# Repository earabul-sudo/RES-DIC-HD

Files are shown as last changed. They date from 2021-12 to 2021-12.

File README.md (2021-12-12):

# Residual Stress Measurement Device using Hole Drilling Method and Digital Image Correlation
 Complete documentation (CAD, Software, Instructions) of a novel Residual Stress Measurement Device utilising Hole Drilling Method and Digital Image Correlation



The CAD Model for the device can be found in the link:
https://a360.co/3m0amRs

For getting started using the device, follow the instructions manual.

Links to additional software used:

  Device/Data Acquisation Related:
  
https://github.com/grbl/grbl (Grbl Gcode parser)

https://github.com/winder/Universal-G-Code-Sender (GUI for Grbl)

https://www.theimagingsource.com/support/downloads-for-windows/end-user-software/icmeasure/ (For capturing images and viewing using camera)

  DIC/Evaluation Related:
  
http://www.ncorr.com/ (Main DIC Software used)

http://mech.fsv.cvut.cz/~nezerka/DIC/index.htm (Plugin for ncorr, allows for creating virtual extensometers)

https://uk.mathworks.com/matlabcentral/fileexchange/50994-digital-image-correlation-and-tracking (Another DIC software, used image averaging functionality in the measurements)

https://imagej.nih.gov/ij/ (Useful tool for image averaging/rigid body corrections)

https://www.irfanview.com/ (Useful tool for batch processing images)

For any issues, contact Ege Arabul (ege.arabul@bath.edu)

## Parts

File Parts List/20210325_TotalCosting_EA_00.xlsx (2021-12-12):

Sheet: Act. Cost
No | Subsystem | Quantity | Part Name | Cost per piece | Total Cost
1 | DIC System | 1 | HAYEAR 48MP Digital Industrial Video Microscope Camera + 100X C-mount Lens + 56 LED Ring Light For Soldering Repair+ Stand Holder | 108.55 | 108.55
2 |  | 1 | 110V-220V 56 LED Ring Light | £16.26 | 16.26
3 | Drilling System | 1 | TACKLIFE Rotary Tool Kit | 35.99 | 35.99
4 |  | 1 | 1.6mm Tungsten Carbide PCB Drill Bit | 8.59 | 8.59
5 | Speckle Pattern Application | 1 | Plasti-kote 3101 400ml Super Spray Paint - Matt Black | £9.34 | 9.34
6 |  | 1 | Plasti-kote 3100SE 400ml Super Matt Spray Paint - White | £5.02 | 5.02
7 | The Actuation | 2 | T8 Trapezoidal Lead Screw Lead Screw + T8 Nut | £8.99 | 17.98
8 |  | 2 | 5mm to 8mm Shaft Coupling | £6.49 | 12.98
9 |  | 2 | Nema 17 Stepper Motor | £10.00 | 20
10 |  | 4 | LML12B Miniature Linear Rail Guide 150 | £14.49 | 57.96
11 |  | 2 | EasyDriver Shield Stepper Motor Driver | £5.99 | 11.98
12 |  | 1 | Mechanical Endstop Limit Switch | £6.99 | 6.99
13 |  | 1 | Arduino Uno | £9.99 | 9.99
14 |  | 1 | Lithium Grease | £5.06 | 5.06
15 | Chip Blower | 1 | One Channel Relay | £1.50 | 1.5
16 |  | 1 | Micro Air Pump - DC 12V Micro Vacuum Pump, Electric Mini Air Pumping Booster for Treatment Instrument | £13.10 | 13.1
17 |  | 1 | Mist Lubrication Coolant Spray System | £5.59 | 5.59
18 | Zero Depth Detection | 1 | Alligator Clips Clamps | £1.99 | 1.99
19 | Sample Attachment | 1 | 52 mm suction cup with M4 screw | £6.49 | 6.49
20 | Packaging | 26 | RS PRO 15 x 15mm 2 Hole Steel Angle Bracket | 0.183 | 4.758
21 |  | 1 | RS PRO M3 x 12mm Hex Socket Cap Screw Black, Self-Colour Steel (Pack of 100) | 13.98 | 13.98
22 |  | 1 | RS PRO Steel, Hex Nut, M3 | 4.02 | 4.02
23 |  | 1 | Zinc Plated Steel Plain Washer, 0.5mm Thickness, M3 | 1.11 | 1.11
24 |  | 1 | Manufacturing Expenses (for the Final prototype) | 50 | 50
 |  |  |  | Total Cost | 429.228

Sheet: Red. Cost
No | Subsystem | Quantity | Part Name | Cost per piece | Total Cost
1 | DIC System | 1 | HAYEAR 48MP Microscope Camera + 100X C-mount Lens + 56 LED Ring Light For Soldering Repair+ Stand Holder | 108.55 | 108.55
2 | Drilling System | 1 | TACKLIFE Rotary Tool Kit | 35.99 | 35.99
3 |  | 1 | 1.6mm Tungsten Carbide PCB Drill Bit | 8.59 | 8.59
4 | Speckle Pattern Application | 1 | Plasti-kote 3101 400ml Super Spray Paint - Matt Black | £5.02 | 5.02
5 |  | 1 | Plasti-kote 3100SE 400ml Super Matt Spray Paint - White | £5.02 | 5.02
6 | The Actuation | 2 | T8 Trapezoidal Lead Screw Lead Screw + T8 Nut | £8.99 | 17.98
7 |  | 2 | 5mm to 8mm Shaft Coupling | £6.49 | 12.98
8 |  | 2 | Nema 17 Stepper Motor | £10.00 | 20
9 |  | 4 | LML12B Miniature Linear Rail Guide 150 | £7.99 | 31.96
10 |  | 2 | EasyDriver Shield Stepper Motor Driver | £5.99 | 11.98
11 |  | 1 | Mechanical Endstop Limit Switch | £6.99 | 6.99
12 |  | 1 | Arduino Uno | £9.99 | 9.99
13 |  | 1 | Lithium Grease | £5.06 | 5.06
14 | Zero Depth Detection | 1 | Alligator Clips Clamps | £1.99 | 1.99
15 | Sample Attachment | 1 | 52 mm suction cup with M4 screw | £6.49 | 6.49
16 | Packaging | 26 | RS PRO 15 x 15mm 2 Hole Steel Angle Bracket | 0.183 | 4.758
17 |  | 1 | RS PRO M3 x 12mm Hex Socket Cap Screw Black, Self-Colour Steel (Pack of 100) | 13.98 | 13.98
18 |  | 1 | RS PRO Steel, Hex Nut, M3 | 4.02 | 4.02
19 |  | 1 | Zinc Plated Steel Plain Washer, 0.5mm Thickness, M3 | 1.11 | 1.11
20 |  | 1 | Manufacturing Expenses (for the Final prototype) | 50 | 50
 |  |  |  | Total Cost | 362.458

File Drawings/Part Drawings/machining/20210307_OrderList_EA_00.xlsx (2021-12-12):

No | Quantity | Part Name | Description | Not Yet Completed/ Completed
1 | 2 | 20210305_LeadScrewNut_EA_00 | LeadScrew Nut
2 | 1 | 20210302_CameraHolder | Camera Holder
3 | 3 | 20212026_SpacerRods_EA_100mm_00 Drawing | Spacer 100mm
4 | 3 | 20212026_SpacerRods_EA_50mm_00 | Spacer 50mm
5 | 3 | 20210226_SpacerBottom_EA_00 | Spacer Bottom
6 | 3 | AB90B_M-Step | Custom Angle Bracket

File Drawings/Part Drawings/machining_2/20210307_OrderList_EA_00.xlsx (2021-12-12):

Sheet: Order_1
No | Quantity | Part Name | Description | Not Yet Completed/ Completed
1 | 2 | 20210305_LeadScrewNut_EA_00 | LeadScrew Nut
2 | 1 | 20210302_CameraHolder | Camera Holder
3 | 3 | 20212026_SpacerRods_EA_100mm_00 Drawing | Spacer 100mm
4 | 3 | 20212026_SpacerRods_EA_50mm_00 | Spacer 50mm
5 | 3 | 20210226_SpacerBottom_EA_00 | Spacer Bottom
6 | 3 | AB90B_M-Step | Custom Angle Bracket

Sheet: Order_2
No | Quantity | Part Name | Description | Not Yet Completed/ Completed
1 | 1 | 20210316_BreadboardBase_EA_00 | Breadboard Mounting Base
2 | 2 | 20210317_JawClamp_1Clamp_EA_00 | Clamp to attach to Breadboard
3 | 1 | 20210317_JawClamp_2Clamps_EA_00 | Clamp to attach to Breadboard
4 | 3 | 20212026_SpacerRods_EA_50mm_00 | Modification to previously made spacers. Parts will be provided
5 | 3 | 20212026_SpacerRods_100mm_EA_00 | Modification to previously made spacers. Parts will be provided
6 | 3 | 20212026_SpacerRods_EA_125mm_00 | Spacer 125 mm
7 | 3 | 20212026_SpacerRods_EA_200mm_00 | Spacer 200 mm

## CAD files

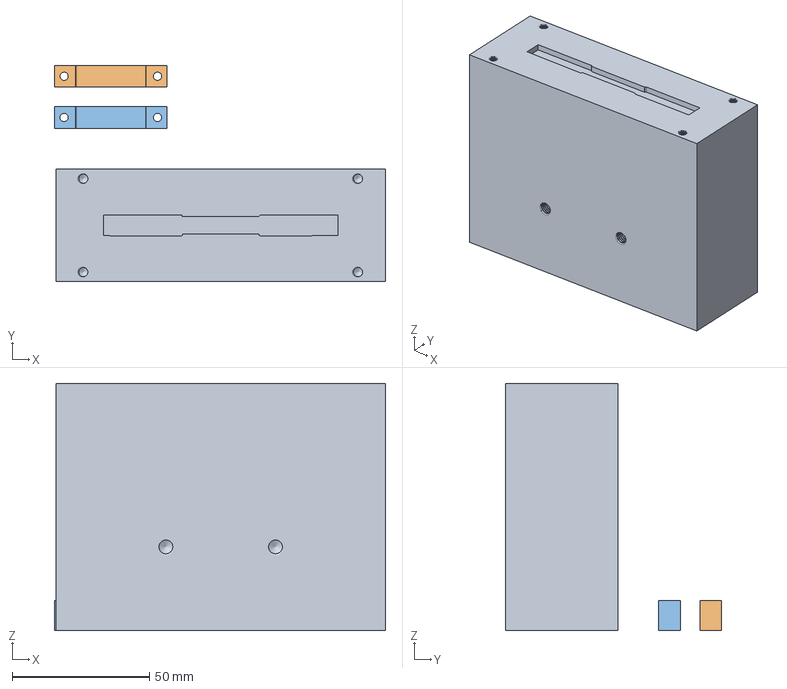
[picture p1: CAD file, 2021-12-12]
Drawings/Part Drawings/3dprint_clamps/CE3PRO_20210302_SecondPrototype2_Assembly_Additiv_Cont_EA_00_20210513_FlexHolder_EA_00 v6.3mf
120.5 x 78.8 x 90.0 mm
20210302_SecondPrototype2_Assembly_Additiv_Cont_EA_00_20210513_FlexHolder_EA_00 v6.stl
20210513_FlexHolderClamp_EA_00 v2.stl
20210513_FlexHolderClamp_EA_00 v2.stl(1)

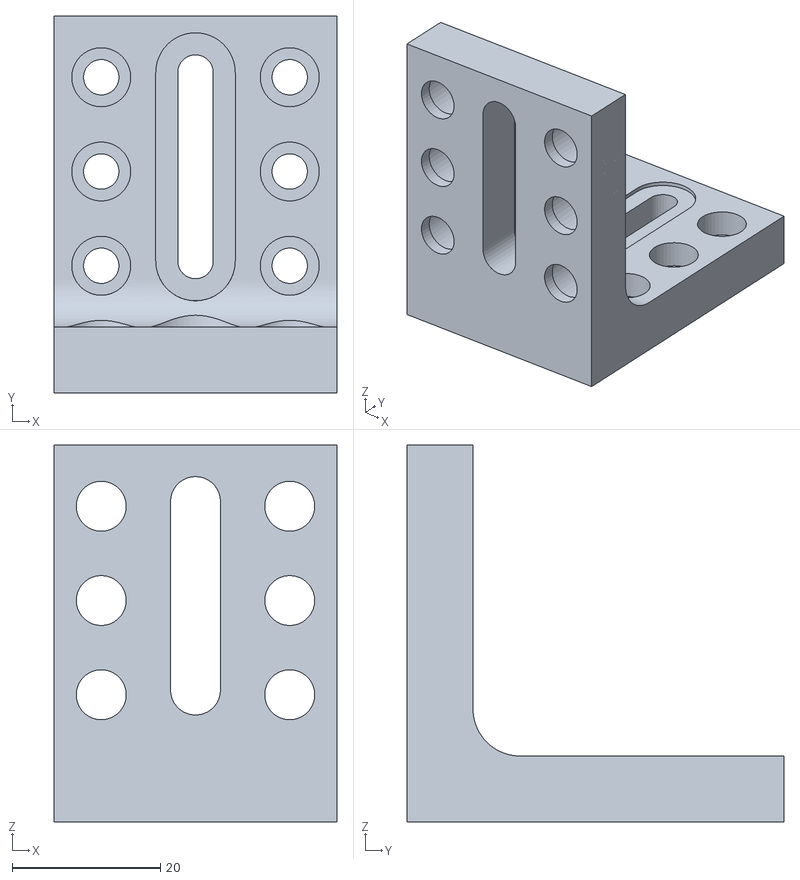
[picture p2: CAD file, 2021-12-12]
Drawings/Part Drawings/3dprint_clamps/AB90D-Step v2.stl
38.1 x 50.8 x 50.8

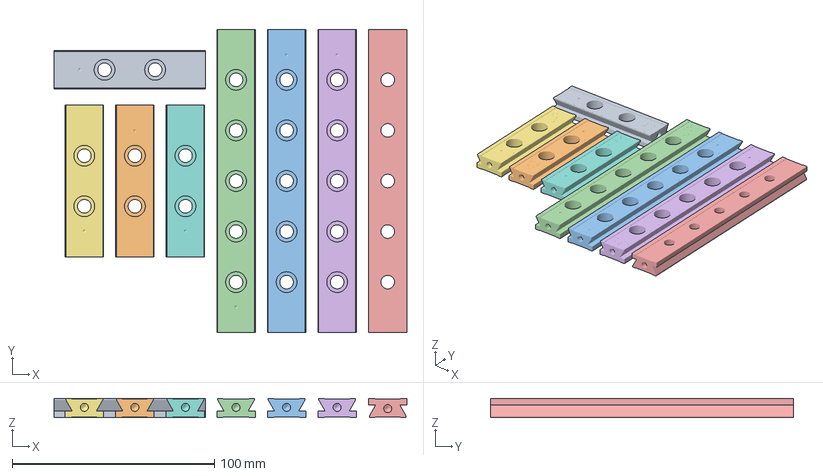
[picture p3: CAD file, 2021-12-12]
Drawings/Part Drawings/3dprint_clamps/CE3PRO_RLA075_M-Step v1.4mf.3mf
174.5 x 150.0 x 9.53 mm
RLA075_M-Step v1.stl
RLA075_M-Step v1.stl(1)
RLA150_M-Step v1.stl
RLA150_M-Step v1.stl(1)
RLA150_M-Step v1.stl(2)
RLA150_M-Step v1.stl(3)
RLA075_M-Step v1.stl(2)
RLA075_M-Step v1.stl(3)

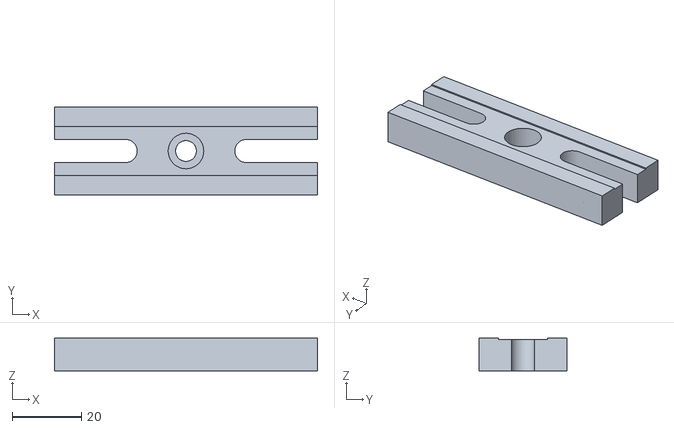
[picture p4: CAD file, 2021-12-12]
Drawings/Part Drawings/3dprint_clamps/BA1V-Step v3.stl
76.2 x 25.4 x 9.53

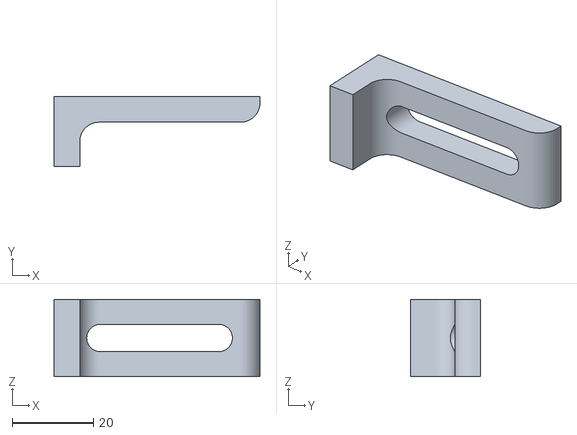
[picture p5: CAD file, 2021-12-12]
Drawings/Part Drawings/3dprint_clamps/CL5-Step v1.stl
50.8 x 17.3 x 19.1

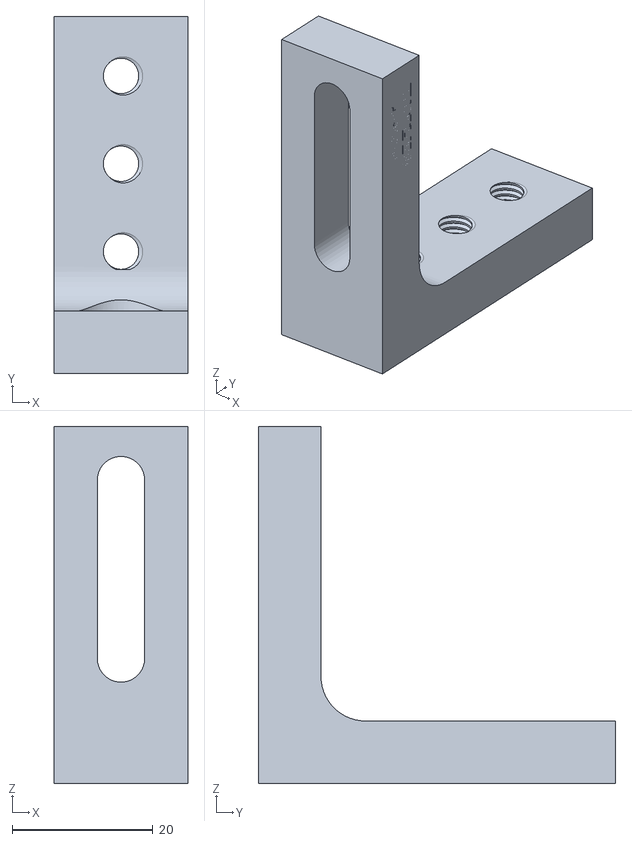
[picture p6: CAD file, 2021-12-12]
Drawings/Part Drawings/3dprint_clamps/AB90C_M-Step v2.stl
19.0 x 50.8 x 50.8

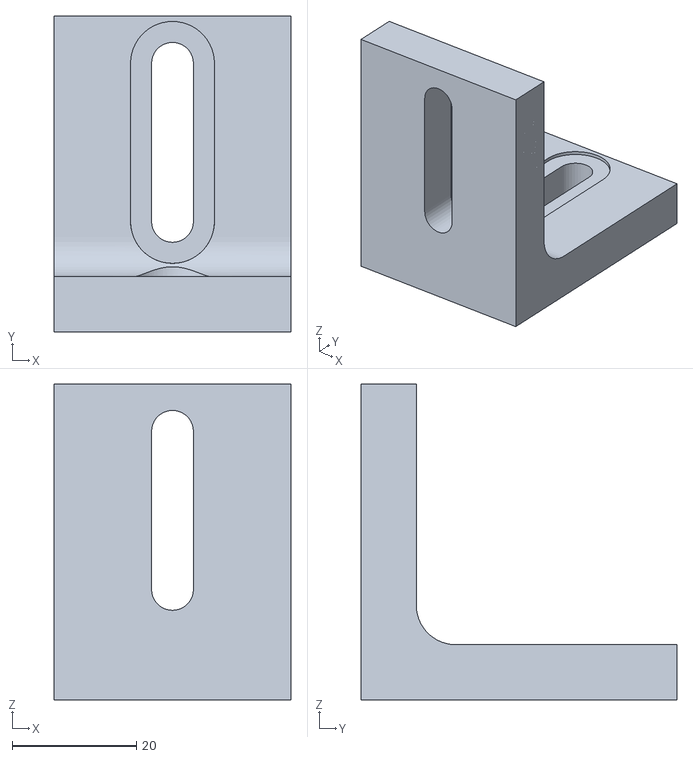
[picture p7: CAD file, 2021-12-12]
Drawings/Part Drawings/3dprint_clamps/AB90-Step v1.stl
38.1 x 50.8 x 50.8

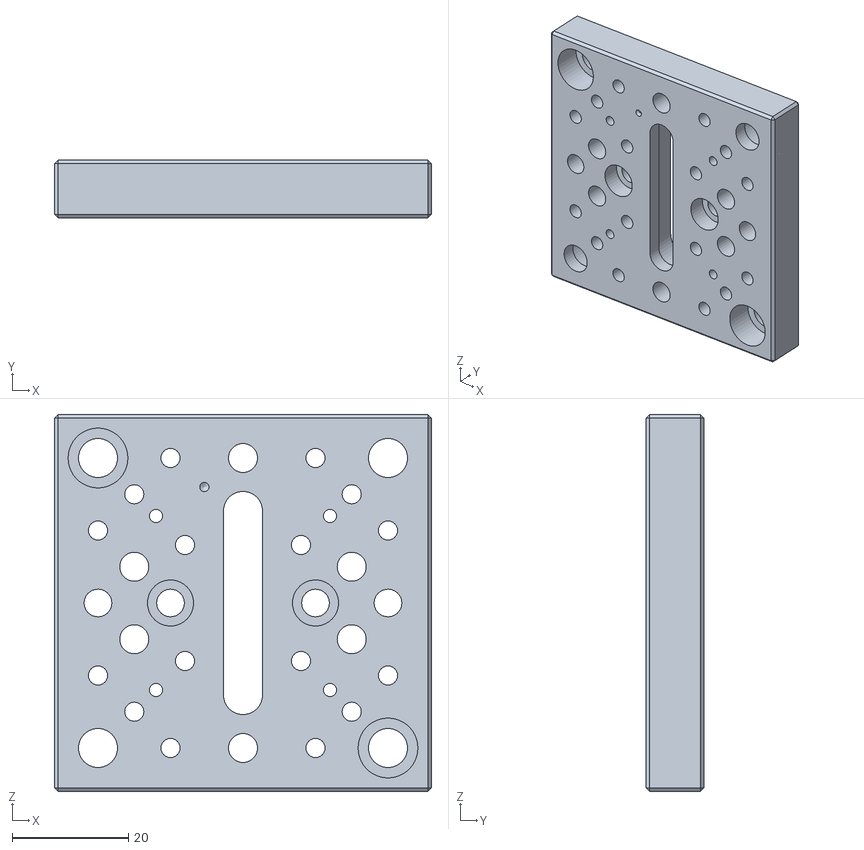
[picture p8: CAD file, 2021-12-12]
Drawings/Part Drawings/3dprint_clamps/UBP2_M-Step v1.stl
65.0 x 10.0 x 65.0

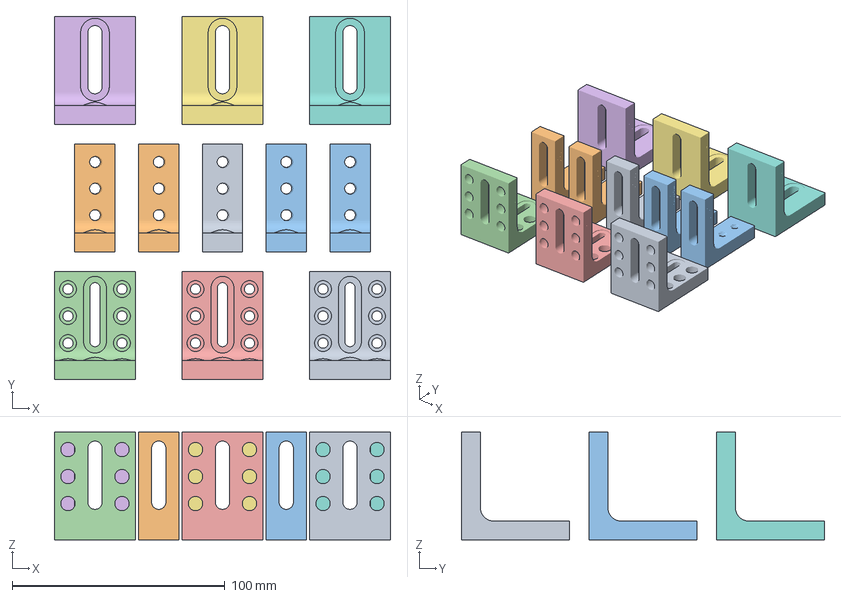
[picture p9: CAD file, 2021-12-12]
Drawings/Part Drawings/3dprint_clamps/CE3PRO_AB90C_M-Step v2.3mf
158.1 x 170.8 x 50.8 mm
AB90C_M-Step v2.stl
AB90C_M-Step v2.stl(1)
AB90C_M-Step v2.stl(2)
AB90D-Step v2.stl
AB90D-Step v2.stl(1)
AB90-Step v1.stl
AB90-Step v1.stl(1)
AB90-Step v1.stl(2)
AB90D-Step v2.stl(2)
AB90C_M-Step v2.stl(3)
AB90C_M-Step v2.stl(4)

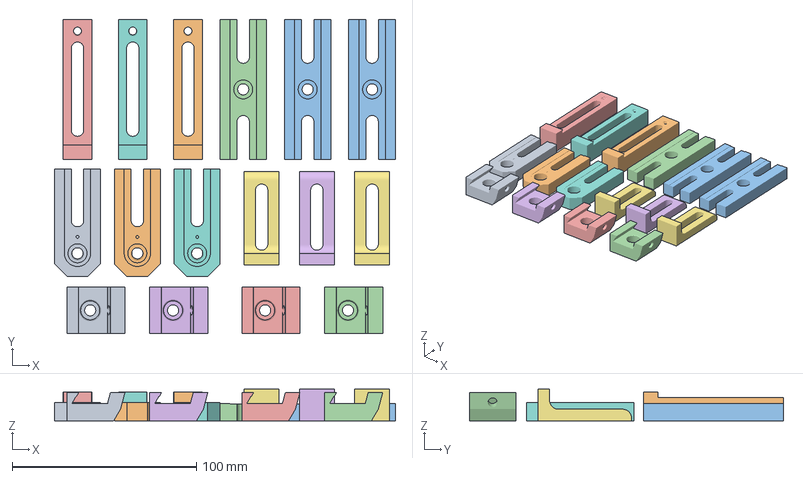
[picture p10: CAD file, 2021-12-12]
Drawings/Part Drawings/3dprint_clamps/CE3PRO_BA1SV_M-Step v2.3mf
185.2 x 170.8 x 17.3 mm
BA1SV_M-Step v2.stl
BA1SV_M-Step v2.stl(1)
BA1V-Step v3.stl
BA1V-Step v3.stl(1)
CL2_M-Step v3.stl
CL5-Step v1.stl
CL5-Step v1.stl(1)
CL2_M-Step v3.stl(1)
RC1-Step v5.stl
CL2_M-Step v3.stl(2)
BA1V-Step v3.stl(2)
RC1-Step v5.stl(1)
RC1-Step v5.stl(2)
RC1-Step v5.stl(3)
CL5-Step v1.stl(2)
BA1SV_M-Step v2.stl(2)

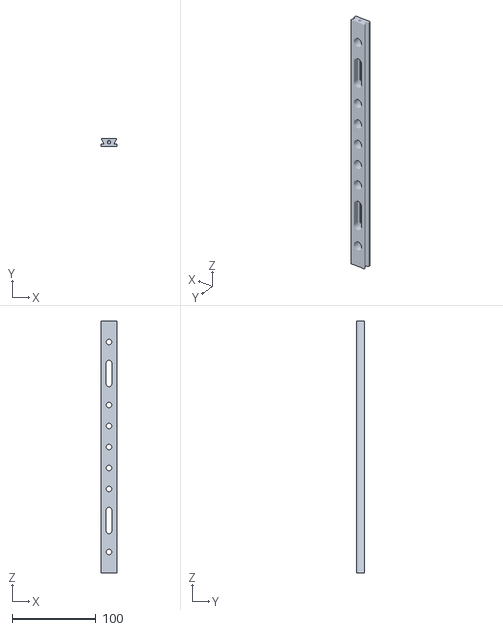
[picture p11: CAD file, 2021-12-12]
Drawings/Part Drawings/3dprint_clamps/RLA300_M-Step v1.stl
19.0 x 9.53 x 300.0

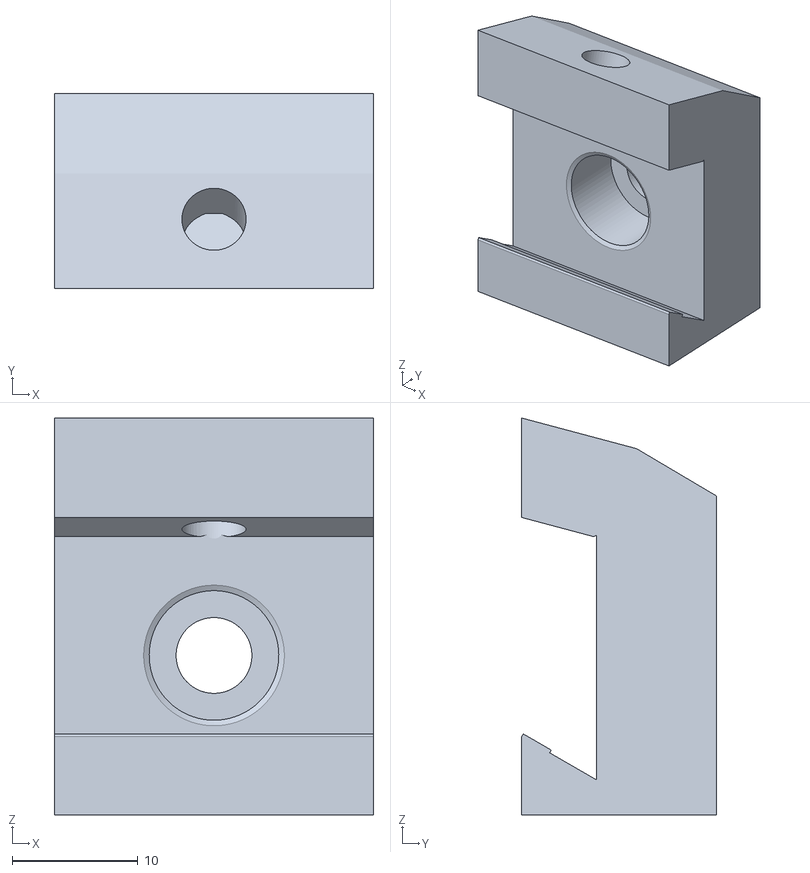
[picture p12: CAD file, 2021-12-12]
Drawings/Part Drawings/3dprint_clamps/RC1-Step v5.stl
25.4 x 15.5 x 31.6

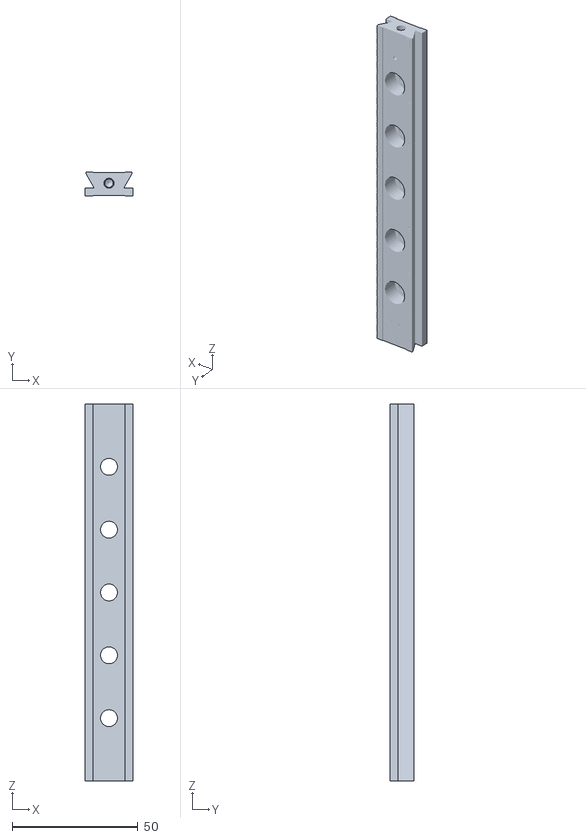
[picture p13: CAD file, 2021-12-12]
Drawings/Part Drawings/3dprint_clamps/RLA150_M-Step v1.stl
19.0 x 9.53 x 150.0

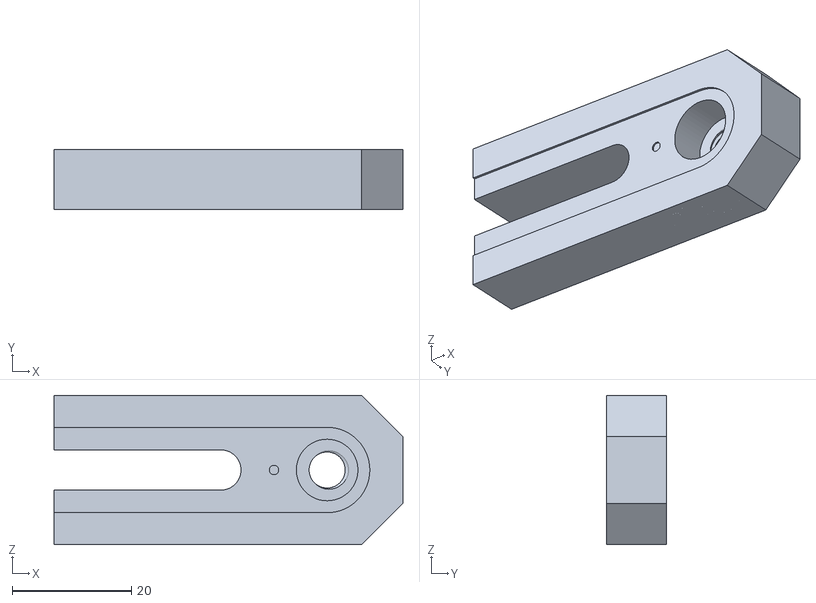
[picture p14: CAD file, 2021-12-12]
Drawings/Part Drawings/3dprint_clamps/BA1SV_M-Step v2.stl
58.4 x 10.0 x 25.0

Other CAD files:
Drawings/Part Drawings/3dprint_clamps/RLA075_M-Step v1.stl
Drawings/Part Drawings/3dprint_clamps/CL2_M-Step v3.stl
Drawings/Part Drawings/3dprint_clamps/20210302_SecondPrototype2_Assembly_Additiv_Cont_EA_00_20210513_FlexHolder_EA_00 v6.stl
Drawings/Part Drawings/3dprint_clamps/20210302_SecondPrototype2_Assembly_Additiv_Cont_EA_00_20210513_FlexHolder_Long_EA_00 v3.stl
Drawings/Part Drawings/3dprint_clamps/20210513_FlexHolderClamp_EA_00 v1.stl
Drawings/Part Drawings/3dprint_clamps/20210513_FlexHolderClamp_EA_00 v2.stl
Drawings/Part Drawings/3dprint_clamps/20210513_FlexHolder_EA_00 v4.stl

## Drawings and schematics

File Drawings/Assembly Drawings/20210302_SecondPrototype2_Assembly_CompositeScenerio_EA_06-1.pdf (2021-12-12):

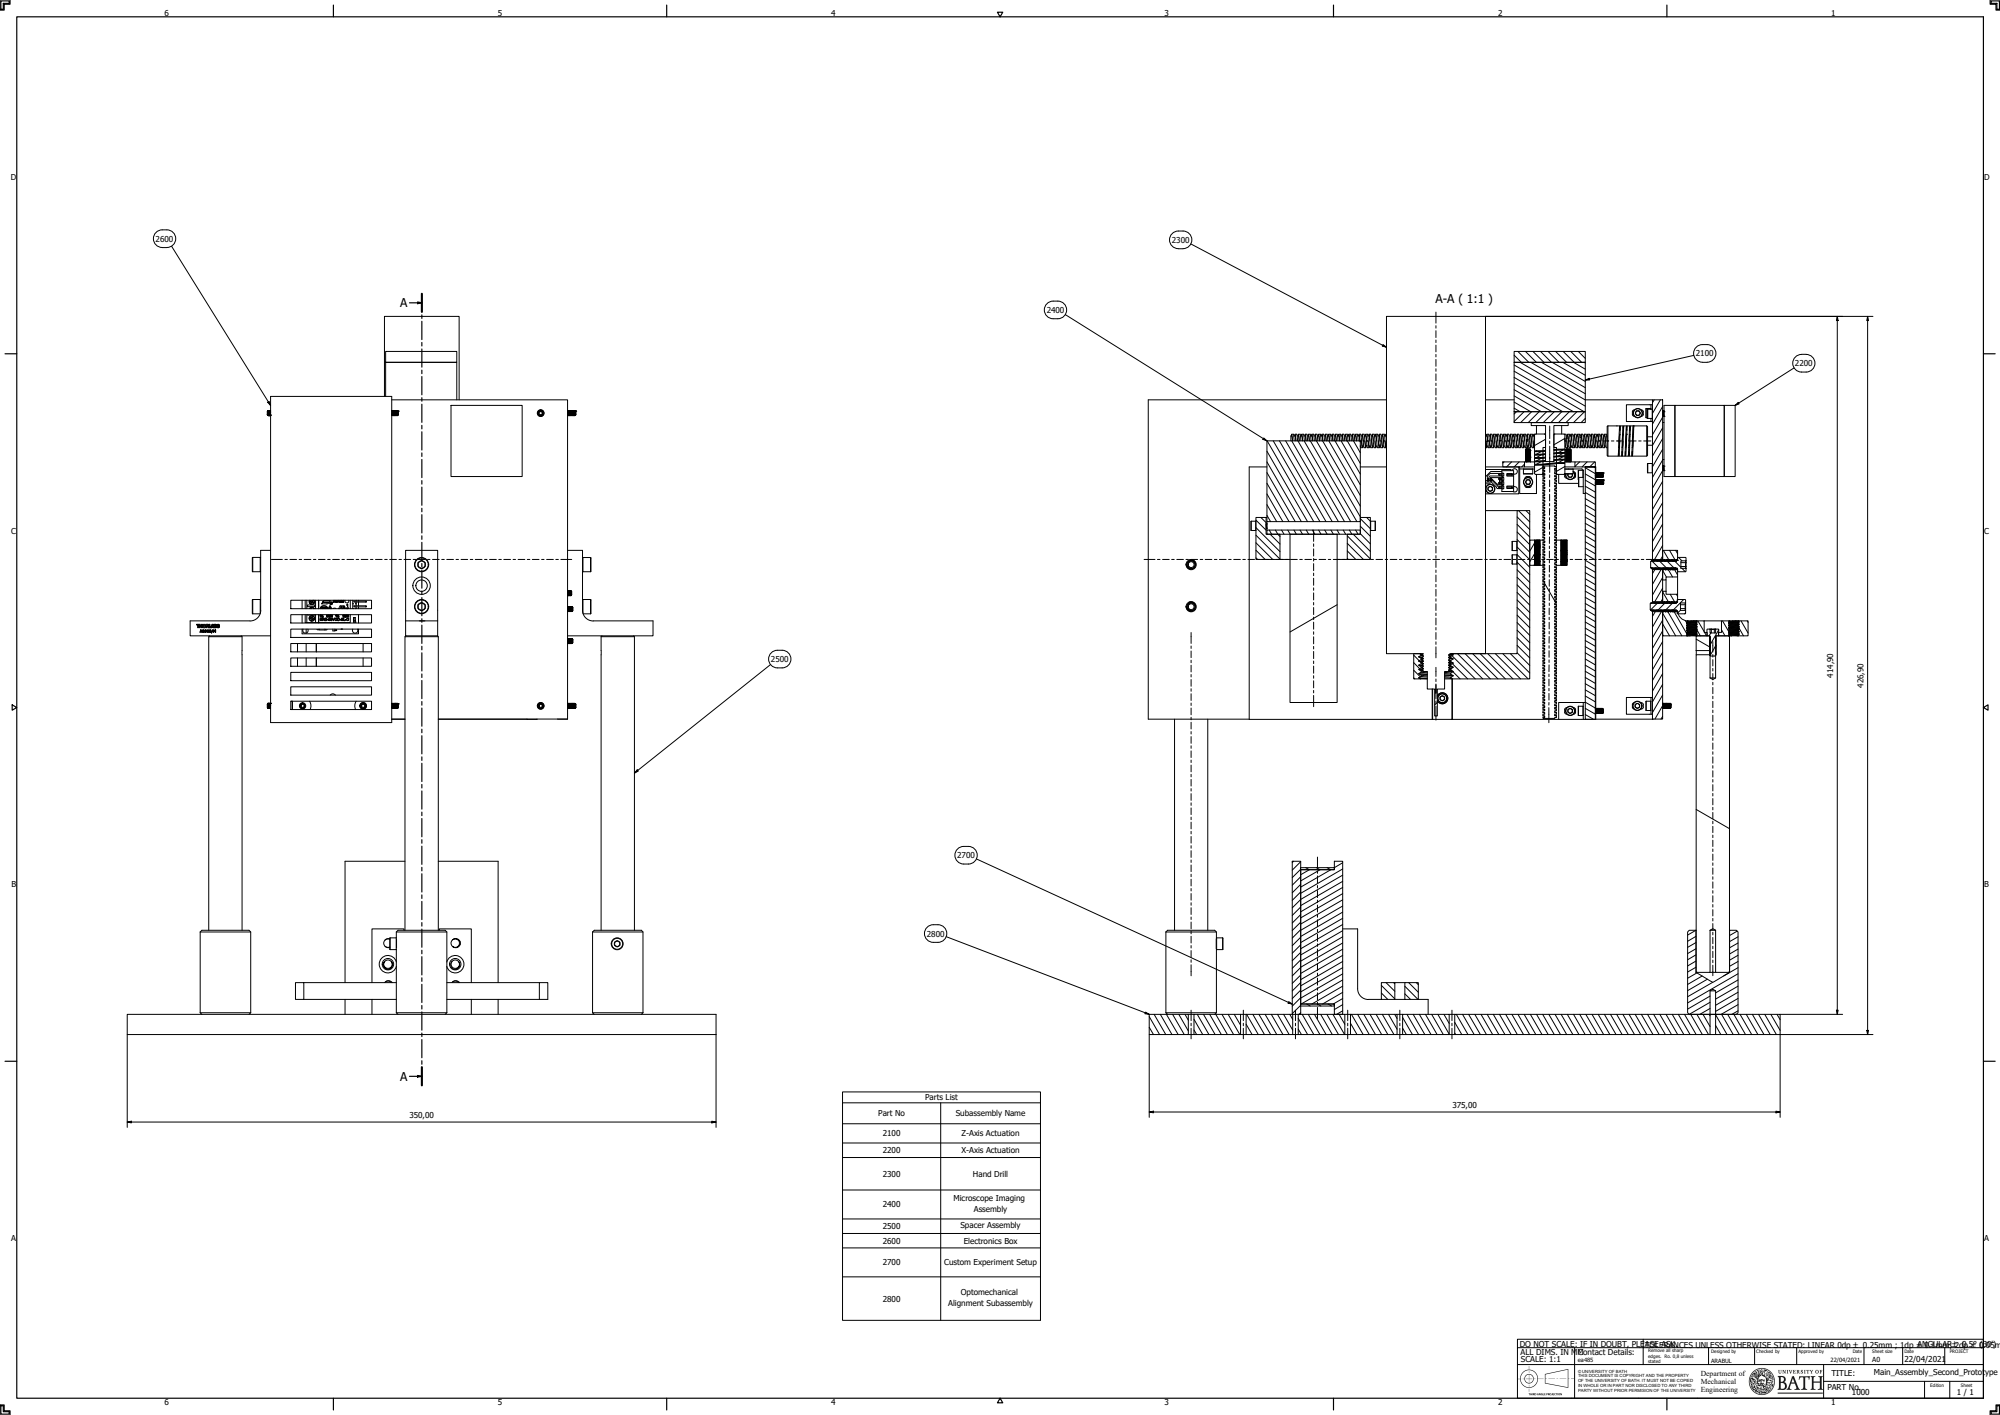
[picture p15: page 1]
Designed by; Checked by; Approved by; Date; Department of; SCALE: 1:1; Sheet size; PART No.; Contact Details:; Parts List; Part No; Subassembly Name; Z-Axis Actuation; X-Axis Actuation; Hand Drill; Microscope Imaging; Spacer Assembly; Electronics Box; Custom Experiment Setup; Alignment Subassembly

DO NOT SCALE: IF IN DOUBT, PLEASE ASK.
ALL DIMS. IN MM

TOLERANCES UNLESS OTHERWISE STATED: LINEAR 0dp  0.25mm ; 1dp ±AN0G.1UmLAmR;2d0p.5±° 0(3.005')mm

Remove all sharp
edges. Ro. 0,8 unless
stated

© UNIVERSITY OF BATH
THIS DOCUMENT IS COPYRIGHT AND THE PROPERTY
OF THE UNIVERSITY OF BATH. IT MUST NOT BE COPIED
IN WHOLE OR IN PART NOR DISCLOSED TO ANY THIRD
PARTY WITHOUT PRIOR PERMISION OF THE UNIVERSITY

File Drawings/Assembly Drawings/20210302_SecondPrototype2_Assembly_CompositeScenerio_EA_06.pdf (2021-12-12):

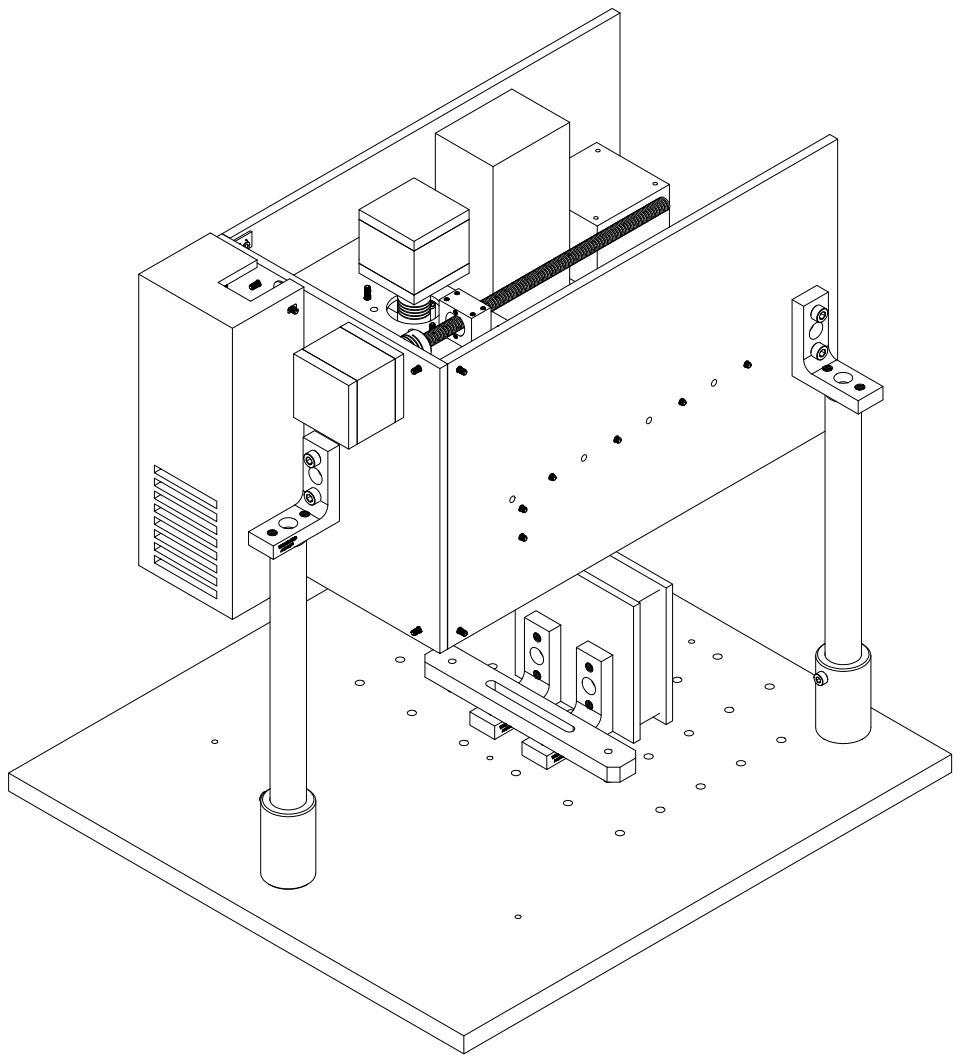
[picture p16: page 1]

DO NOT SCALE | TOLERANCES: LINEAR 0dp  0.25mm ; 1dp ± 0.1mm; 2dp ± 0.05mm ANGULAR 0.5° (30')
DIMS. IN MM SCALE: 1 : 1 | Contact Details: ea485 | Remove all sharp edges. Ro. 0,8 unless stated | Designed by ARABUL | Checked by | Approved by Date 22/04/2021 | Sheet size A0 | Date 22/04/2021 | PROJECT

© UNIVERSITY OF BATH THIS DOCUMENT IS COPYRIGHT AND THE PROPERTY OF THE UNIVERSITY OF BATH. IT MUST NOT BE COPIED IN WHOLE OR IN PART NOR DISCLOSED TO ANY THIRD PARTY WITHOUT PRIOR PERMISION OF THE UNIVERSITY | Department of Mechanical Engineering | TITLE: Main Assembly_Isometric

PART No. 1000 | Edition | Sheet 1 / 1

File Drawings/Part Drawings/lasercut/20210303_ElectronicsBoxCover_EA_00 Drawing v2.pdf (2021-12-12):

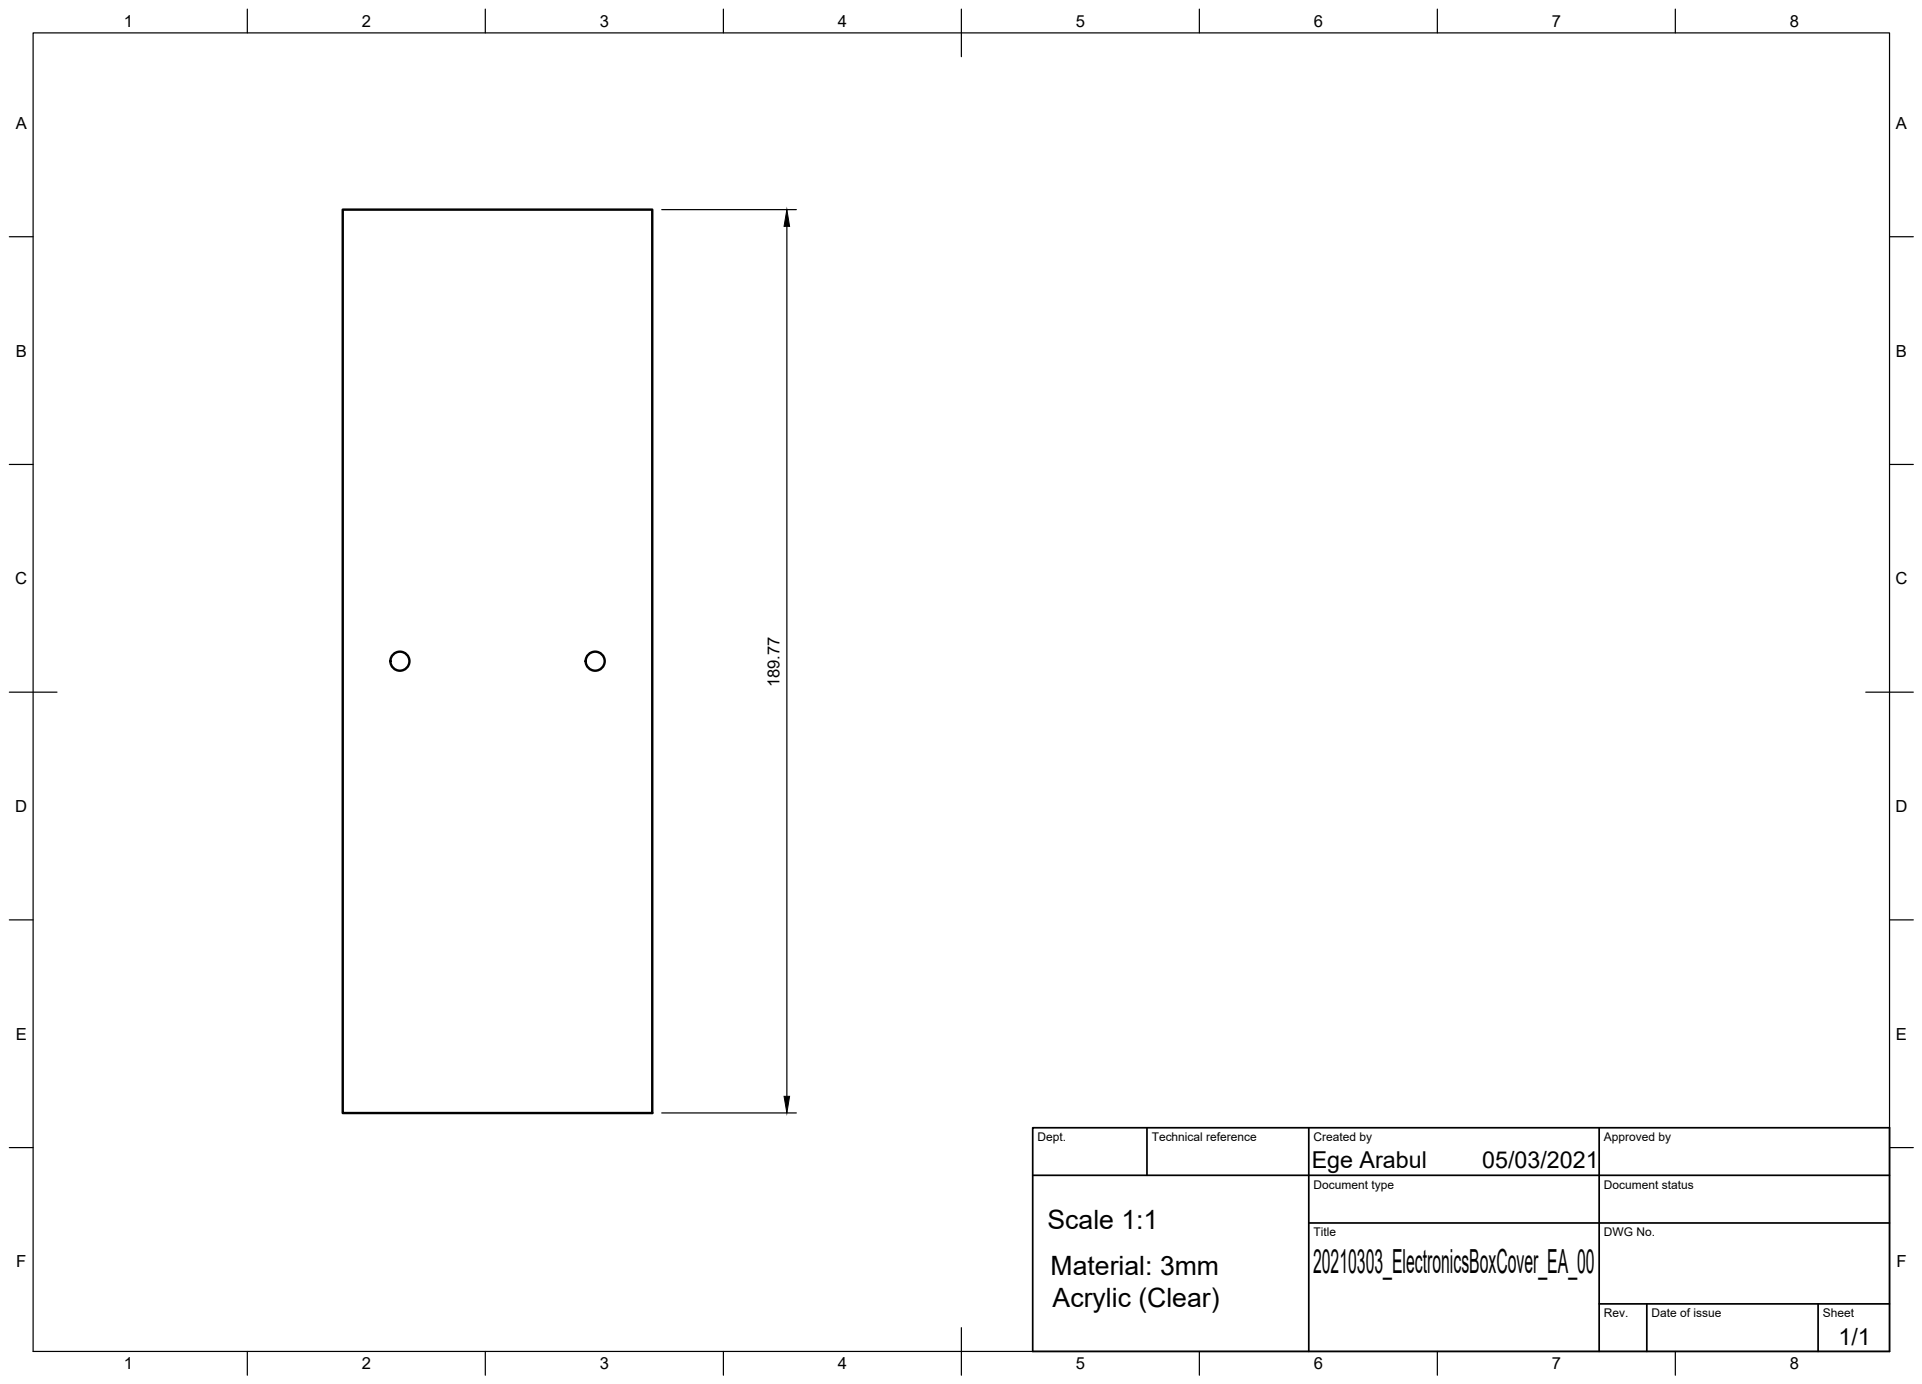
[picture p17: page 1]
Title; DWG No.; Rev.; Date of issue; Sheet; Ege Arabul 189.77; Scale 1:1; Material: 3mm Acrylic (Clear)

Dept. | Technical reference | Created by 05/03/2021 | Approved by

Document type | Document status

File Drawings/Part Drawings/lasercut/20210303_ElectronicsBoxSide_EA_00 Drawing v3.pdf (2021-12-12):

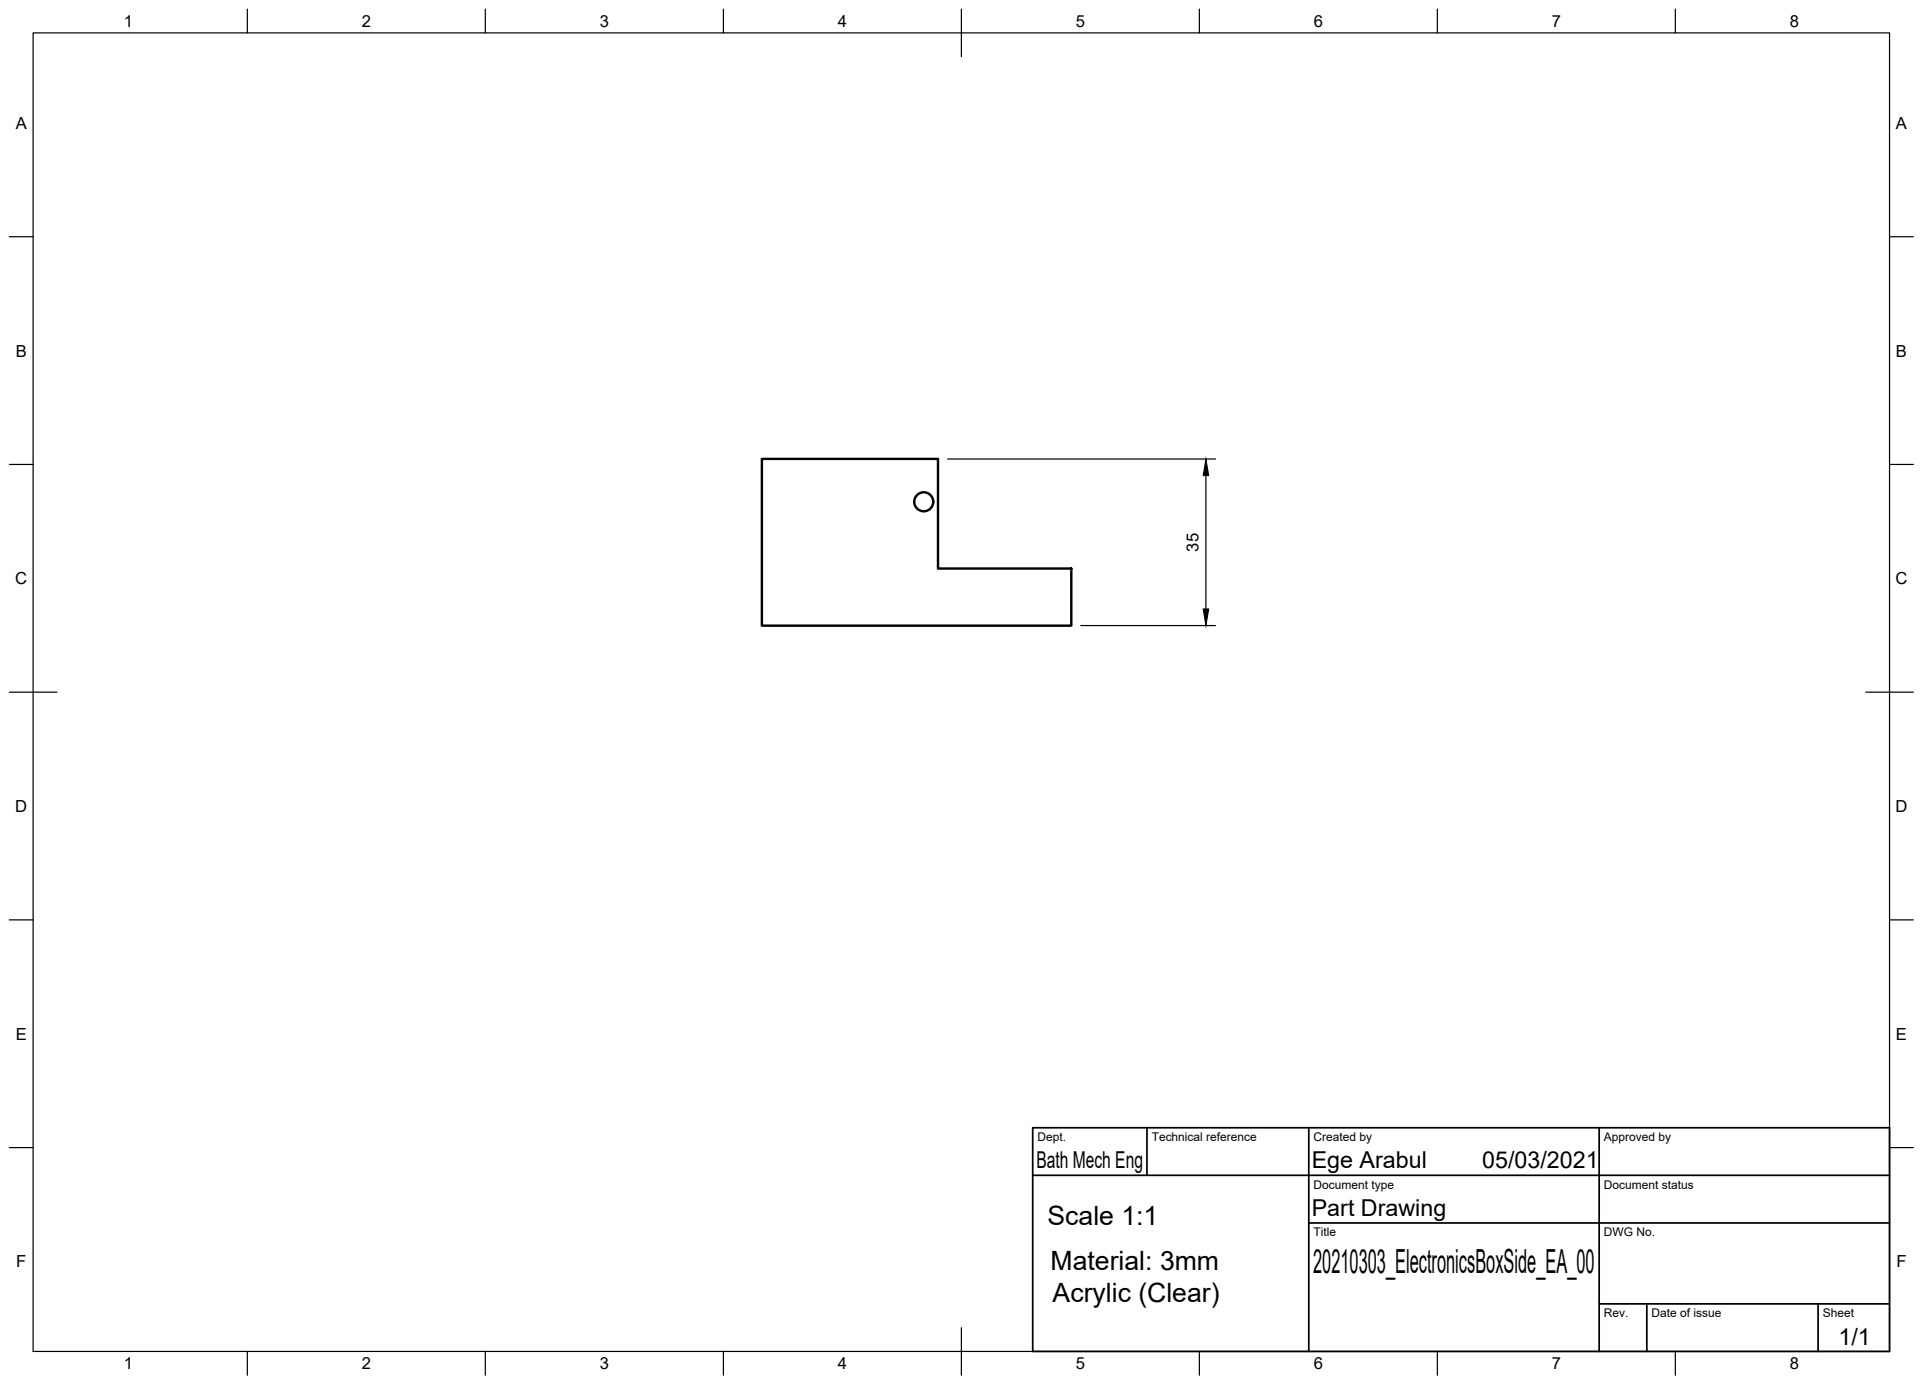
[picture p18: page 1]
Title; DWG No.; Rev.; Date of issue; Sheet; Bath Mech Eng; Ege Arabul 35; Scale 1:1; Material: 3mm Acrylic (Clear)

Dept. | Technical reference | Created by 05/03/2021 | Approved by

Document type Part Drawing | Document status

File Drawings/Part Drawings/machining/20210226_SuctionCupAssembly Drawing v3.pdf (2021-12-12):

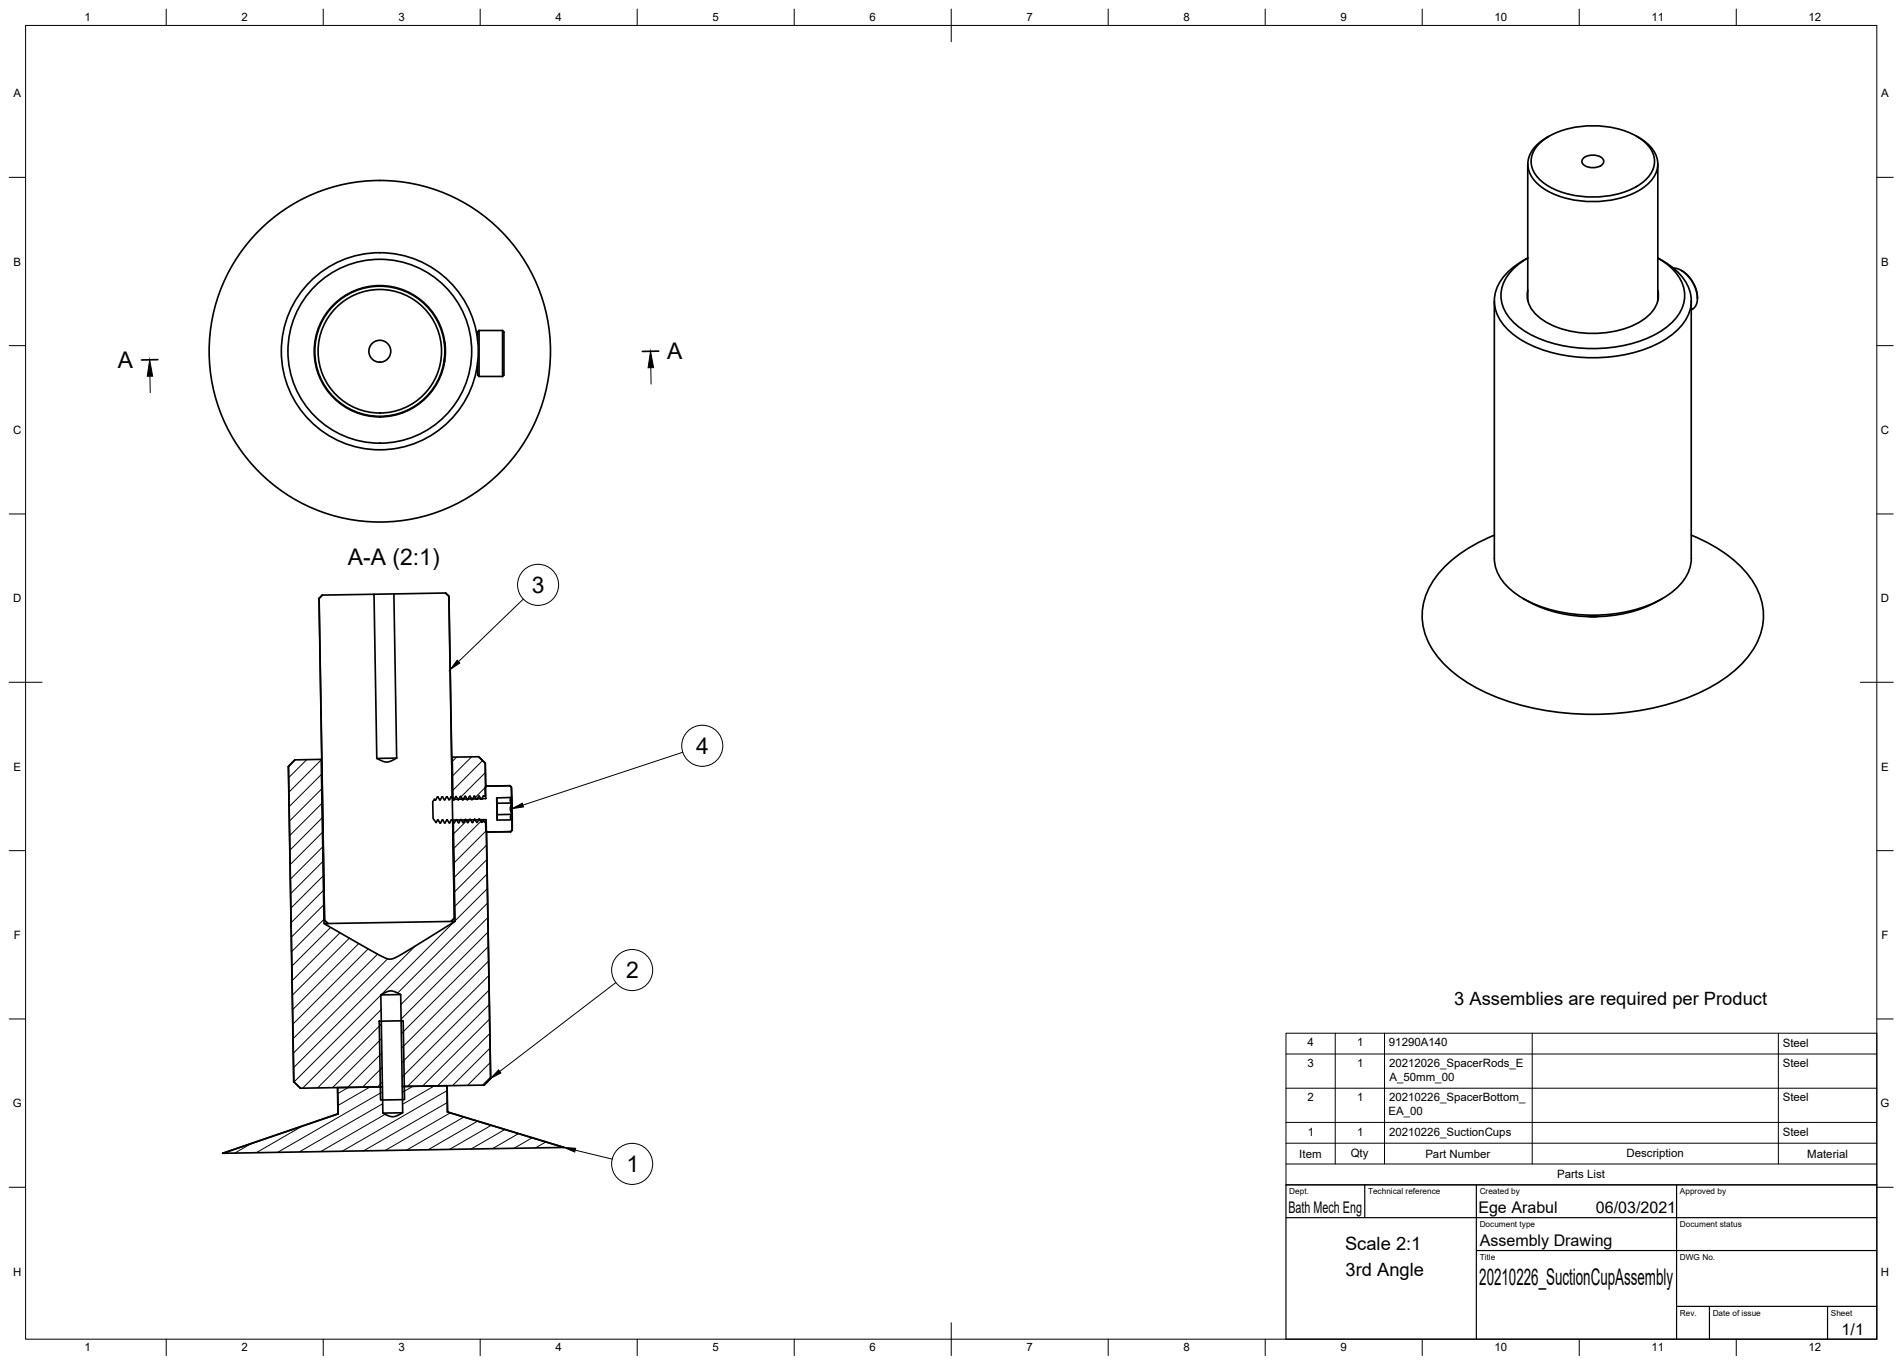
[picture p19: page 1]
Parts List

3 Assemblies are required per Product

4 | 1 | 91290A140 | | Steel
3 | 1 | 20212026_SpacerRods_E A_50mm_00 | | Steel

2 | 1 | 20210226_SpacerBottom_ EA_00 | | Steel

1 | 1 | 20210226_SuctionCups | | Steel

Item | Qty | Part Number | Description | Material

Dept. Bath Mech Eng | Technical reference | Created by Ege Arabul 06/03/2021 | Approved by

Scale 2:1 3rd Angle | | Document type Assembly Drawing | Document status

Title 20210226_SuctionCupAssembly | DWG No.

Rev. | Date of issue | Sheet 1/1

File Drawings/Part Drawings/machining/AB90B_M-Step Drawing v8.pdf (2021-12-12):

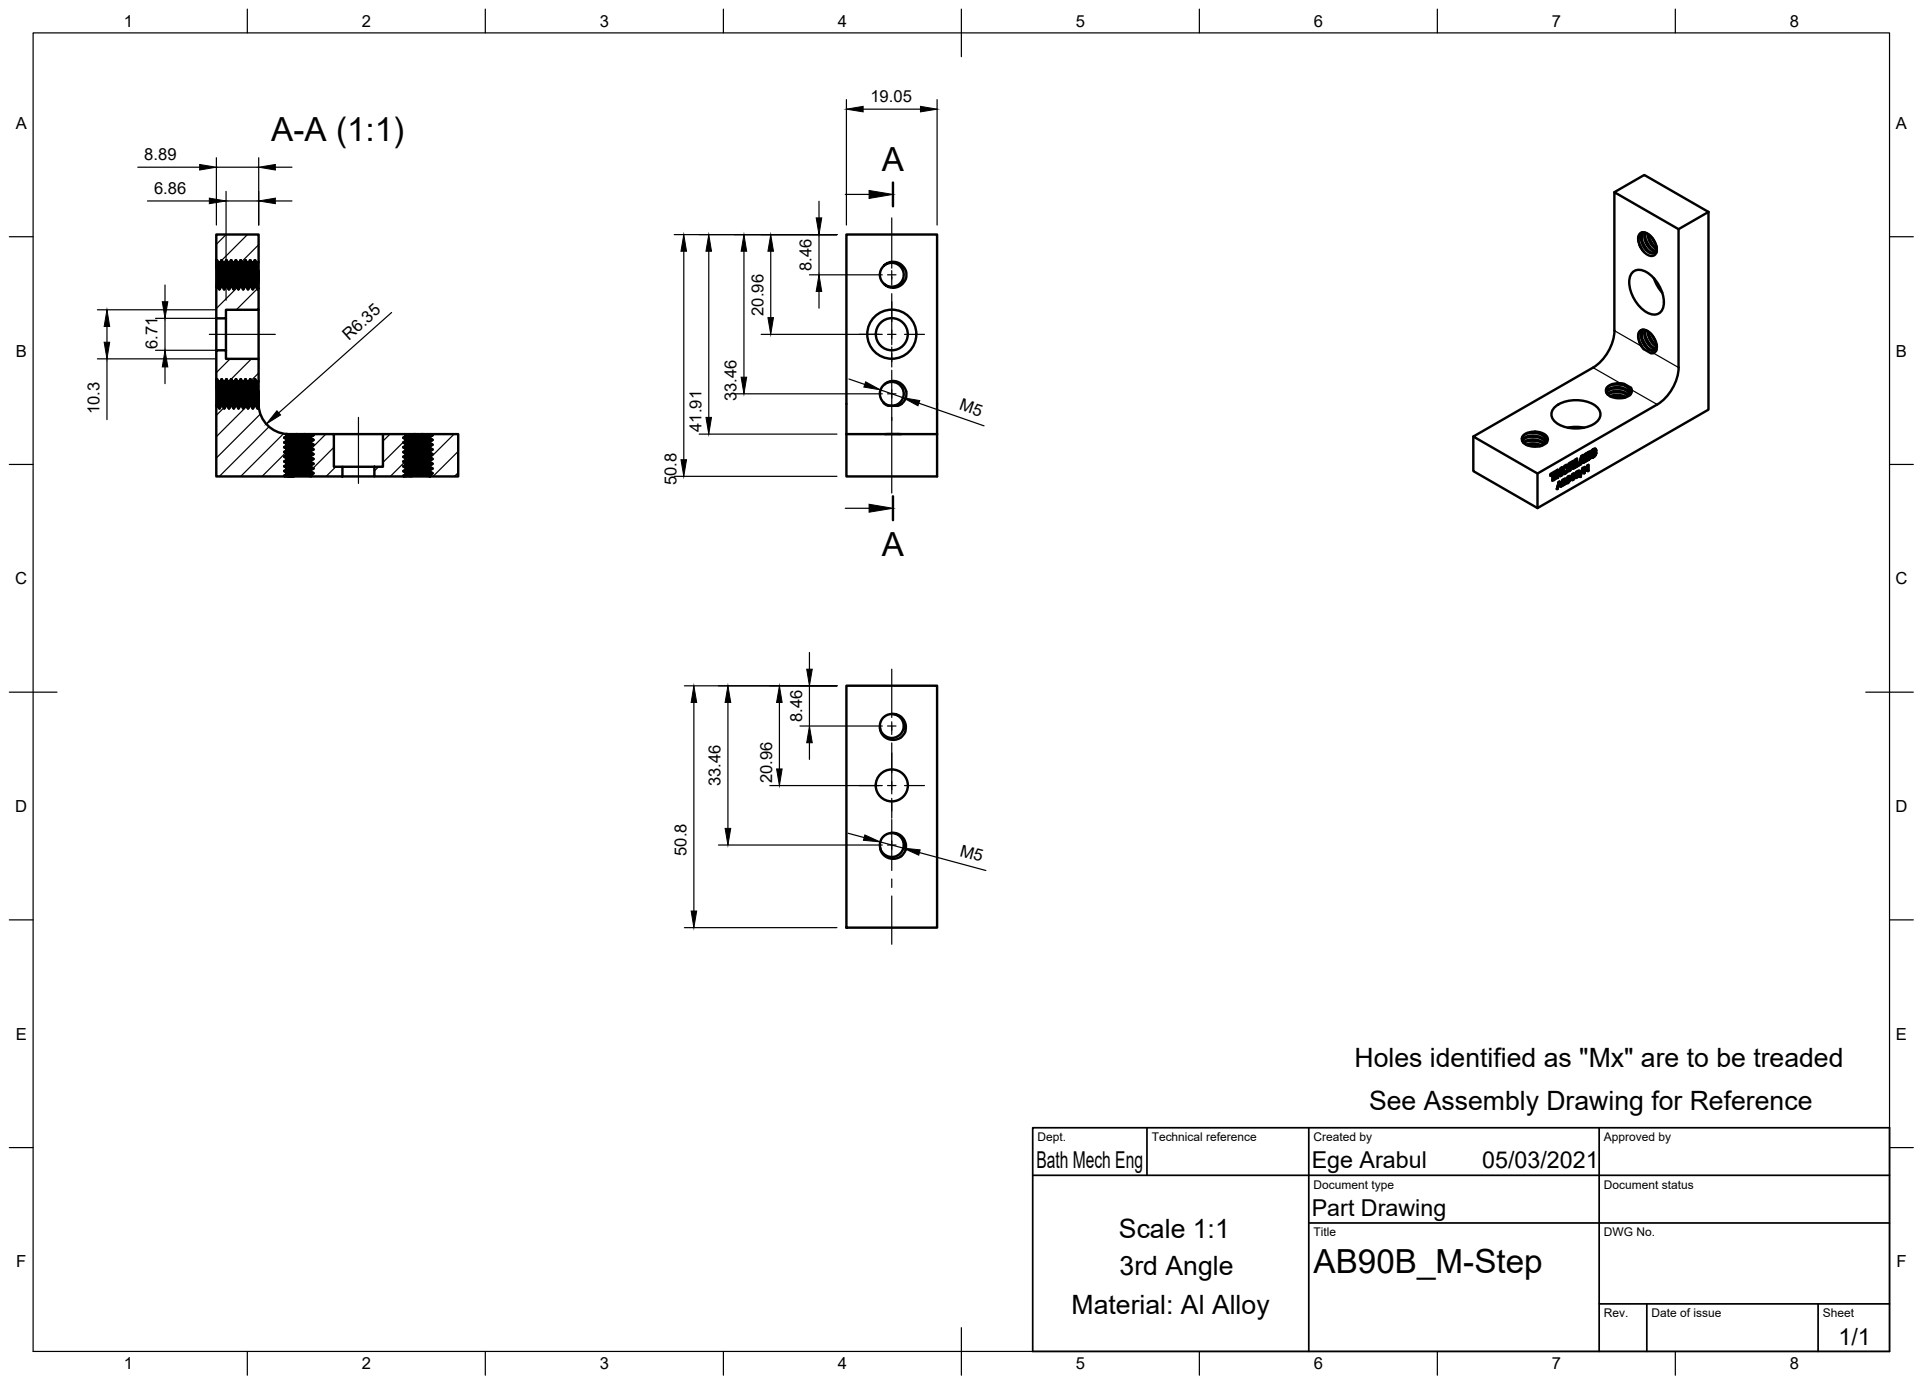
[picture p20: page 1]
Title; DWG No.; Rev.; Date of issue; Sheet

Holes identified as "Mx" are to be treaded
See Assembly Drawing for Reference

Dept. Bath Mech Eng | Technical reference | Created by Ege Arabul 05/03/2021 | Approved by

Document type Part Drawing | Document status

Scale 1:1
3rd Angle
Material: Al Alloy

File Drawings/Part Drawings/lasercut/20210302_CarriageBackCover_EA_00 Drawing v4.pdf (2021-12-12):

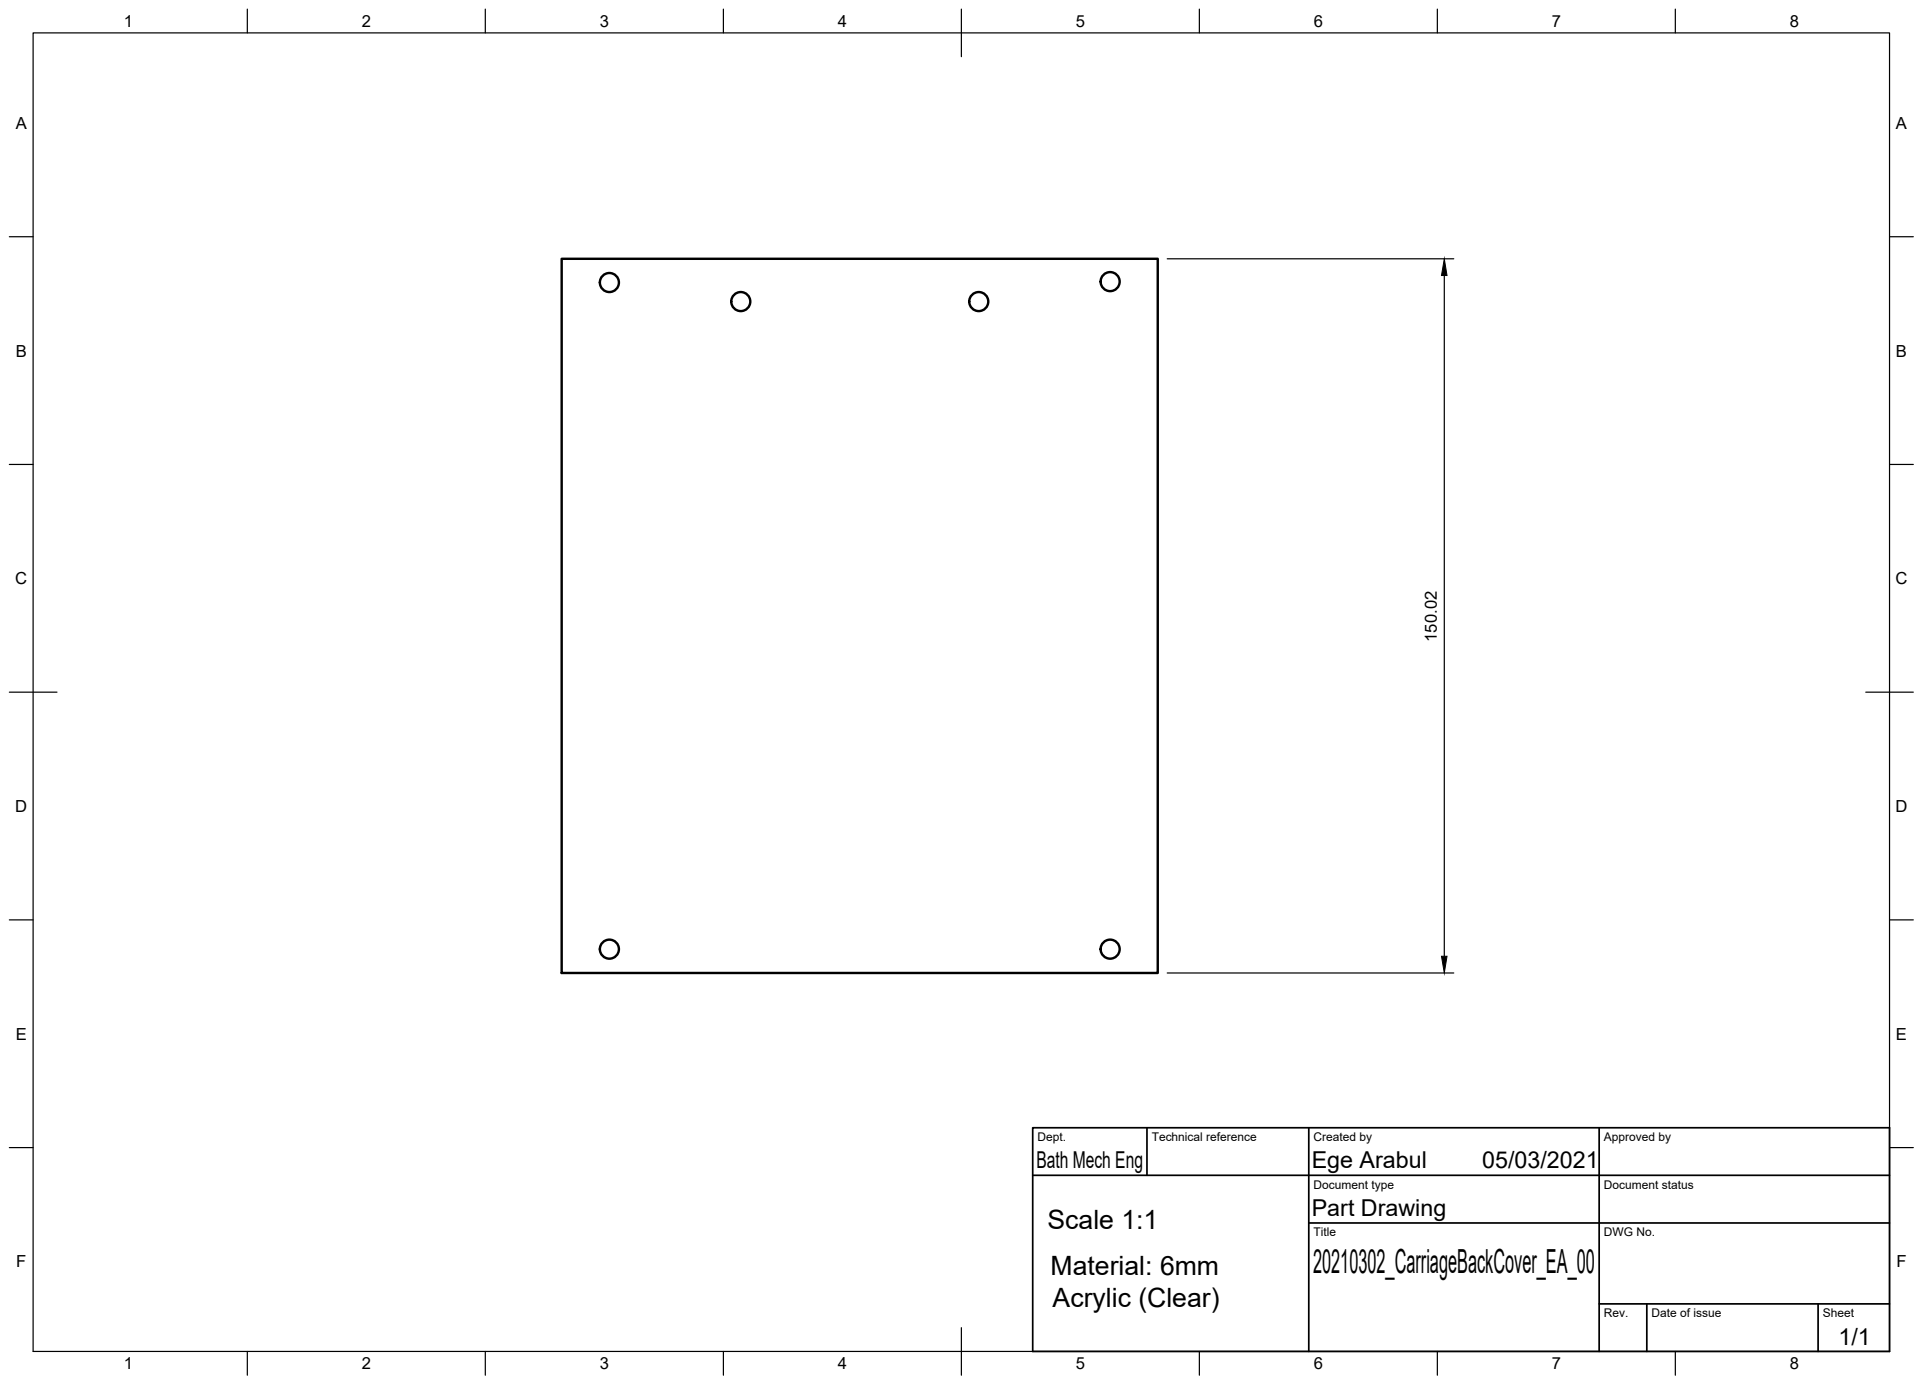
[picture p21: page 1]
Title; DWG No.; Rev.; Date of issue; Sheet; Bath Mech Eng; Ege Arabul 150.02; Material: 6mm Acrylic (Clear); Scale 1:1

Dept. | Technical reference | Created by 05/03/2021 | Approved by

Document type Part Drawing | Document status

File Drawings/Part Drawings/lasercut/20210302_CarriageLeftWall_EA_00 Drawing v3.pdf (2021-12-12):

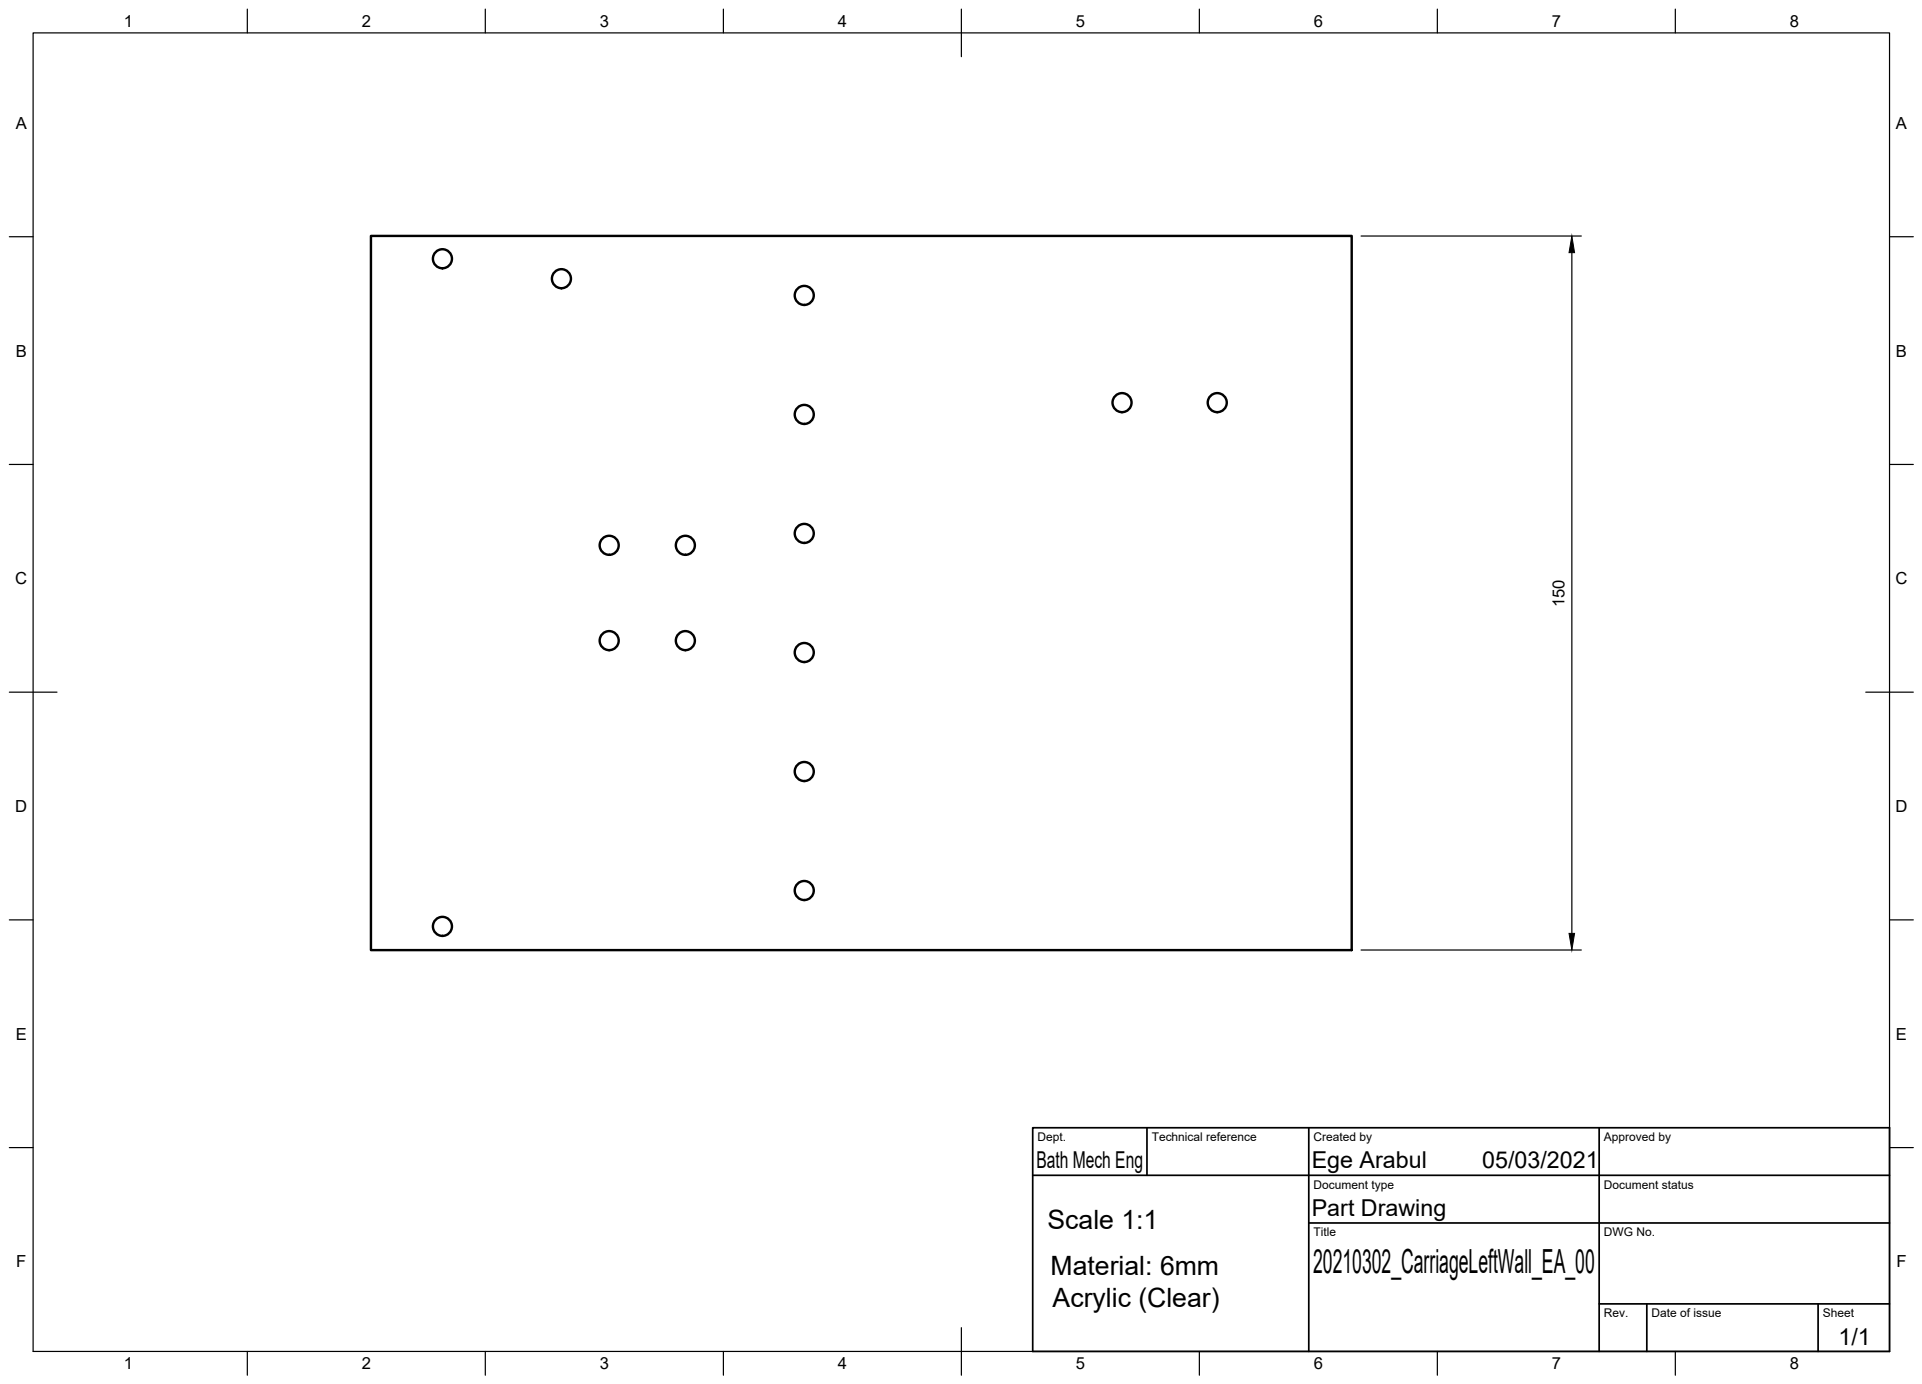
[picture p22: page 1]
Title; DWG No.; Rev.; Date of issue; Sheet; Bath Mech Eng; Ege Arabul; Scale 1:1; Material: 6mm Acrylic (Clear)

Dept. | Technical reference | Created by 05/03/2021 | Approved by

Document type Part Drawing | Document status

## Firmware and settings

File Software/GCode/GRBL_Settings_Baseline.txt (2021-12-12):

$0 = 10    (Step pulse time, microseconds)
$1 = 25    (Step idle delay, milliseconds)
$2 = 0    (Step pulse invert, mask)
$3 = 0    (Step direction invert, mask)
$4 = 0    (Invert step enable pin, boolean)
$5 = 0    (Invert limit pins, boolean)
$6 = 0    (Invert probe pin, boolean)
$10 = 1    (Status report options, mask)
$11 = 0.010    (Junction deviation, millimeters)
$12 = 0.002    (Arc tolerance, millimeters)
$13 = 0    (Report in inches, boolean)
$20 = 0    (Soft limits enable, boolean)
$21 = 1    (Hard limits enable, boolean)
$22 = 1    (Homing cycle enable, boolean)
$23 = 0    (Homing direction invert, mask)
$24 = 25.000    (Homing locate feed rate, mm/min)
$25 = 500.000    (Homing search seek rate, mm/min)
$26 = 250    (Homing switch debounce delay, milliseconds)
$27 = 1.000    (Homing switch pull-off distance, millimeters)
$30 = 1000    (Maximum spindle speed, RPM)
$31 = 0    (Minimum spindle speed, RPM)
$32 = 0    (Laser-mode enable, boolean)
$100 = 200.000    (X-axis travel resolution, step/mm)
$101 = 200.000    (Y-axis travel resolution, step/mm)
$102 = 200.000    (Z-axis travel resolution, step/mm)
$110 = 500.000    (X-axis maximum rate, mm/min)
$111 = 500.000    (Y-axis maximum rate, mm/min)
$112 = 500.000    (Z-axis maximum rate, mm/min)
$120 = 10.000    (X-axis acceleration, mm/sec^2)
$121 = 10.000    (Y-axis acceleration, mm/sec^2)
$122 = 10.000    (Z-axis acceleration, mm/sec^2)
$130 = 200.000    (X-axis maximum travel, millimeters)
$131 = 200.000    (Y-axis maximum travel, millimeters)
$132 = 200.000    (Z-axis maximum travel, millimeters)

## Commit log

2021-12-12 Create Assembly Drawings
2021-12-12 Moved Drawings under part drawing
    [20210302_SecondPrototype2_Assembly_Additiv_Cont_EA_00_20210513_FlexHolder_EA_00 v6.stl, 20210302_SecondPrototype2_Assembly_Additiv_Cont_EA_00_20210513_FlexHold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]
2021-12-12 Moved under Drawings
    [20210302_SecondPrototype2_Assembly_Additiv_Cont_EA_00_20210513_FlexHolder_EA_00 v6.stl, 20210302_SecondPrototype2_Assembly_Additiv_Cont_EA_00_20210513_FlexHold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]
2021-12-12 Eval and GCode Scripts used
    [GRBL_Settings_Baseline.txt, GRBL_Settings_New.txt]
